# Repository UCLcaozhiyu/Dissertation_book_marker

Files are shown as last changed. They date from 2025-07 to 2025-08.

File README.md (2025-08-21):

#  From Smart Bookmark to Intelligent Bookstand Low-Power Embedded System Design for Enhanced Paper-Based Reading

An intelligent reading-time tracking device based on ESP32 that automatically recognizes different books through NFC, records reading time, and provides Pomodoro timer, statistical analysis, and other features.

Originally conceived as an ultra-thin solar-powered smart bookmark, the project evolved into a desktop-style smart bookstand to overcome energy and hardware constraints while enhancing usability and user experience.

##  Key Features

###  Multi-Book Management
- Support for tracking up to 10 books independently
- Automatic book recognition and switching via NFC cards
- Individual reading statistics for each book
- Persistent data storage, no data loss on power off

###  Smart Tracking
- Automatic reading state detection via light sensor
- Real-time reading time recording
- Adaptive Pomodoro timer functionality
- Personalized reading habit analysis

###  Power-Efficient Design
- Smart deep sleep mode (only 10μA power consumption)
- Adaptive wake-up intervals (1-5 minutes)
- Dual wake-up mechanism: GPIO and timer
- Intelligent I2C bus management

###  User Interaction
- 128x64 OLED display
- Pixel art style UI design
- Real-time trend graph of ambient light，dynamic wave animation effects
- Buzzer notifications for reading/rest prompts
- Real-time status indicators

##  Hardware Requirements

### Core Components
- **MCU**: ESP32-C3 / ESP32 WROOM-32D
- **Display**: SSD1306 OLED (128x64, I2C interface)
- **NFC Module**: PN532 (I2C interface)
- **Light Sensor**: Light Dependent Resistor (LDR)
- **Audio**: Active buzzer module (HYT-0905)
- **Power**: BQ24074 charging + Li-ion battery + optional solar panel

Power Options

Monocrystalline solar panel (5V) → sustainable indoor charging

USB Type-C → backup fast charging

Battery: 401020 Li-ion (~120 mAh)

Earlier prototypes attempted OPV flexible solar panels for true bookmark size, but lab tests showed insufficient indoor output (<6 mW @ 500 lux). This led to the shift toward the bookstand form factor with hybrid solar + USB charging.

### Wiring Diagram

```
ESP32 WROOM-32D:
├── OLED SSD1306 (128x64)
│   ├── SDA → GPIO 21
│   ├── SCL → GPIO 22
│   ├── VCC → 3.3V
│   └── GND → GND
├── PN532 NFC Module
│   ├── SDA → GPIO 21 (Shared I2C bus with OLED)
│   ├── SCL → GPIO 22 (Shared I2C bus with OLED)
│   ├── VCC → 3.3V
│   └── GND → GND
├── Light Dependent Resistor (LDR)
│   ├── One end → GPIO 36 (ADC input)
│   ├── Other end → 3.3V
│   └── Pull-down resistor 10kΩ → GND
├── Buzzer Module
│   ├── VCC → 3.3V
│   ├── GND → GND
│   └── Signal → GPIO 5
└── Wake-up Button (Optional)
    ├── One end → GPIO 33
    └── Other end → GND
```

##  Quick Start

### Environment Setup

1. **Install Arduino IDE** (Recommended version 2.0+)
    -Add ESP32 board support via: https://dl.espressif.com/dl/package_esp32_index.json

3. **Add ESP32 Board Support**:
   - File → Preferences → Additional Boards Manager URLs
   - Add: `https://dl.espressif.com/dl/package_esp32_index.json`
   - Tools → Board → Boards Manager → Search "ESP32" and install

4. **Install Required Libraries**:
   ```
   - Adafruit GFX Library
   - Adafruit SSD1306
   - Adafruit PN532
   - ESP32 Preferences
   ```

### Compile and Upload

1. **Select Board**:
   - ESP32 WROOM-32D: `ESP32 Dev Module`
   - ESP32-C3: `ESP32C3 Dev Module`

2. **Configure Parameters**:
   ```
   Upload Speed: 921600
   CPU Frequency: 240MHz (ESP32) / 160MHz (ESP32-C3)
   Flash Mode: DIO
   Flash Size: 4MB
   Partition Scheme: Default 4MB
   ```

3. **Choose Version**:
   - `bookstand v3/bookstand_WROOM_withbetterNFCmanagement/` - ESP32 WROOM-32D version
   - `bookstand v3/WROOM32Ddeepsleepmode/` - Deep sleep optimized version
   - `bookstand v3/finalOLEDtest/finalOLEDv3/` - ESP32-C3 version

##  Functionality

### NFC Book Management
- Place NFC card above the device for automatic book recognition
- First-time use automatically registers new books
- Support for custom book names and information
- Independent timing and statistics for each book

### Reading Detection
- Automatic reading state detection via light sensor
- Smart filtering of ambient light interference
- Adaptive threshold adjustment
- Real-time status feedback

### Pomodoro Timer
- Automatically adjusts duration based on personal reading habits
- Audio notification when timer expires
- Smart break time suggestions
- Focus concentration statistics

### Data Statistics
- Total reading time for each book
- Average reading session duration
- Reading frequency analysis
- Number of completed Pomodoro sessions

##  Advanced Configuration

### Sensor Calibration

Modify in `bookstand_WROOM_withbetterNFCmanagement.ino`:

```cpp
// Light threshold configuration
const int baselineThreshold = 500;    // Base light threshold
const int dynamicRange = 200;         // Dynamic range
const int noiseMargin = 50;           // Noise margin

// Sleep configuration
const unsigned long idleTimeout = 30000;        // Idle timeout (milliseconds)
const unsigned long lowLightSleepDelay = 2000;  // Low light delay (milliseconds)
```

### Book Management

```cpp
#define MAX_BOOKS 10              // Maximum number of books
#define BOOK_NAME_MAX_LENGTH 20   // Maximum book name length
```

### Deep Sleep Optimization

Enable deep sleep functionality to reduce standby power consumption to 10μA:

```cpp
// In WROOM32Ddeepsleepmode version
const unsigned long wakeupInterval = 60000;  // Wake-up interval (milliseconds)
```

## 📊 Version History
| Version | Key Features | Status |
| --- | --- | --- |
| **Bookmark (v1)** | Ultra-thin OPV-powered design, BLE output | ❌ Energy infeasible |
| **Bookstand v1**  | Dock charging, FSR sensor | Deprecated |
| **Bookstand v2**  | OLED + NFC + Pomodoro + solar + Type-C | ✅ Exhibition-tested |
| **Bookstand v3**  | Multi-book tracking, adaptive Pomodoro, I²C arbitration | ✅ Current release |

### v3.0 - Multi-Book Management Version
- ✅ Support for tracking up to 10 books independently
- ✅ Improved NFC management system
- ✅ Book statistics data persistence
- ✅ Smart book switching notifications

### v2.3 - Deep Sleep Optimization
- ✅ True deep sleep mode (10μA power consumption)
- ✅ Smart timer wake-up
- ✅ Adaptive wake-up intervals
- ✅ GPIO wake-up support

### v2.0 - NFC Multi-Book Support
- ✅ NFC card book recognition
- ✅ Independent timing for multiple books
- ✅ OLED pixel art interface
- ✅ I2C bus conflict optimization

## User Study & Feedback

As part of project evaluation, user questionnaires were conducted during an exhibition:

Positive response to reviving obsolete but aesthetically unique objects (e.g., bookmarks, cassette players) with IoT intelligence.

Users preferred standalone functionality (OLED display, buzzer feedback) over BLE-only smartphone integration.

Bookstand v2 was rated the most popular design:

Artistic shell design

Simple & intuitive UI

Reliable NFC book switching

## Research Context

This project originated as a MSc Dissertation at UCL CASA (Connected Environments).

Explores IoT-enablement of traditional reading tools

Tests feasibility of solar-assisted embedded systems in micro form factors

Investigates balance between traditional aesthetics and smart functionality

Informs future IoT retrofits for legacy objects

Related literature includes indoor photovoltaics, low-power embedded system design, and user acceptance of IoT-enabled traditional objects.

## 🐛 Troubleshooting

### Common Issues

**Q: OLED display not working**
- Check I2C connection wires are correct
- Confirm OLED address is 0x3C
- Check power supply is normal

**Q: NFC cannot read cards**
- Confirm PN532 module I2C mode jumper settings
- Check for I2C address conflicts with OLED
- Try different types of NFC cards

**Q: Light detection inaccurate**
- Adjust LDR position to avoid obstruction
- Modify light threshold parameters in code
- Confirm pull-down resistor value is 10kΩ

**Q: Cannot wake up from deep sleep**
- Check GPIO33 pin connection
- Confirm pull-up resistor configuration is correct
- Verify deep sleep wake-up source settings

### Debug Mode

Enable serial debug information:
```cpp
Serial.begin(115200);
// Add debug output in setup()
Serial.println("=== Debug Mode Enabled ===");
```

##  Contributing

Issues and Pull Requests are welcome!

### Development Environment
- Arduino IDE 2.0+
- ESP32 Arduino Core 2.0+
- Git version control

### Commit Convention
- Feature improvements: `feat: add new feature description`
- Bug fixes: `fix: fix issue description`
- Documentation updates: `docs: update documentation content`

##  License

This project is licensed under the MIT License - see the [LICENSE](LICENSE) file for details.

##  Author

**Zhiyu Cao** - Embedded developer and reading enthusiast

##  Acknowledgments

- Adafruit - Excellent hardware library support
- ESP32 Community - Rich development resources
- All testers for valuable feedback

---

**📖 Enjoy smart reading time! If this project helps you, please give us a ⭐️**

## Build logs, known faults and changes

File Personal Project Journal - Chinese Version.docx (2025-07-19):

Intelligent Bookmark for Reading Time Monitoring using Solar Energy and ESP32-C3

设计一款自供电的智能书签设备，通过太阳能供电与ESP32-C3模块，在无人工干预的情况下记录用户的阅读时间与充电数据，并通过BLE连接与手机App通信。

# 系统设计组成

### 1. 供电与能量管理模块

- 电池：401020 锂电池（容量约100mAh）
- 充电管理：TP4056 充电模块（含过充/过放保护版本）
- 能源来源：
  - 太阳能板（柔性、薄型，适配书签厚度限制）
    - 选型偏向 OPV（有机光伏） 或 Amorphous Silicon（非晶硅）
    - OPV 在低光（室内300–500 lux）条件下有更好表现

### 2. 核心控制器

- MCU：ESP32-C3
  - 具备低功耗能力（支持 deep sleep）
  - 支持 BLE通信 与后续数据传输
  - Type-C口供电调试

### 3. 传感系统与记录逻辑

- 主要机制：通过光照变化判断阅读状态
  - 在有光时 → 正在阅读 → 开始计时并记录太阳能充电数据
  - 在无光时 → 书签被夹进书中 → 暂停计时

### 4. 通信接口

- BLE与手机App连接（如Flutter开发）
  - 数据同步（阅读时长、电量记录）
  - 可视化历史趋势图（选项）

# 设计方案与变体

方案 | 描述 | 优势 | 挑战
柔性OPV太阳能板 | 有机材料，轻薄可弯曲 | 适合室内低光；可集成于书签 | 转换效率较低（5-10%）
非晶硅太阳能板 | 成本低，能适应弯曲 | 室内适用，厚度可控 | 效率略低于OPV，部分厚度超标
CIGS | 效率高，性能稳定 | 适合高强度照明 | 厚度大，不适合书签

状态检测逻辑

方法 | 描述 | 评估
环境光判断 | 利用ESP32连接光敏电阻/光照模块检测光线强度 | 简单可实现；易受遮挡/自然光干扰
时间窗口判断 | 设定连续处于亮光状态达x分钟才记录为阅读 | 可排除短暂曝光，逻辑更稳健
加速度计 | 判断书签是否被移动 | 精度低，不如光照直接

通信与数据处理逻辑

方法 | 描述 | 评估
本地记录 + BLE同步 | ESP32记录数据，定时唤醒上传 | 节能有效
实时BLE传输 | 实时传输充电和阅读状态 | 需保持通信活跃，耗电高
离线+日志同步 | 书签离线记录，用户打开App才触发BLE同步 | 更节能，适合日常使用

# 关键技术假设与论证

1. OPV在室内优于硅材料的理论基础

- OPV吸收光谱集中于可见光和弱红外区
- 在室内照明下，其 光响应效率高于晶体硅（后者偏向强日照中的UV/IR）
- 文献支持：室内光（300–500 lux）中，OPV转换效率甚至可达10%以上，优于传统PV的1–3%

2. ESP32-C3 Deep Sleep策略可行性

- Deep Sleep电流<10μA
- 利用外部中断（例如光敏模块）唤醒
- 低功耗+间歇记录模式可实现一周以上续航

3. BLE传输足以满足数据同步

- 数据包量小（每天几个数值：开始时间、结束时间、电量）
- BLE连接时间<2s，支持低频率上传
- 手机端App只在打开时需要连接

# 从太阳能供电转向可充电底座的方案转型

在初步原型设计阶段，本项目尝试通过柔性太阳能板与401020锂电池为智能书签供电，以实现完全自持型的嵌入式监测系统。然而，实际计算与文献分析表明，OPV太阳能板在典型室内照度（300–500 lux）下的功率输出仅为0.5–2mW，远远无法覆盖ESP32-C3的唤醒与BLE通信周期所需能耗，除非以极长周期与极限休眠压缩任务。

此外，光照判断阅读状态也存在不稳定性，容易受自然光干扰或书本遮挡影响。为此，系统可靠性与功耗策略亟需重构。

💡 设计转变：引入可充电底座

为解决上述挑战，本阶段提出用“书架形状”的可充电底座取代太阳能供电系统，通过物理归位接触来同步数据并补充能量。该设计具备以下优势：

- 稳定供电：摆脱对不确定室内光源的依赖，使用5V电源为锂电池充电
- 更清晰的阅读行为判断：书签离开底座 → 阅读开始；归位 → 阅读结束，逻辑更自然
- 减少硬件复杂性：太阳能板和发电效率优化过程可取消，简化布线与封装结构
- 增强原型测试友好性：调试时可通过底座直接供电，无需外接Type-C线

⚙️ 底座设计概念

- 结构：垂直支架或斜插式书签插槽，配有2个金属接触点（pogo pin或磁吸接点）
- 供电方式：外部Type-C电源（5V），经由底座直接为书签内TP4056模块供电
- 附加功能（未来拓展）：
  - 霍尔传感器检测归位动作
  - BLE同步器（底座作为中继或充电提醒设备）
  - LED状态灯指示充电与连接状态

状态 | 行为 | 电源策略 | BLE状态
离开底座 | 记录开始 | 电池供电 | 周期广播
回到底座 | 记录结束 + 数据同步 | 开始充电 | 上传数据/待机
长时间无变化 | Deep Sleep | 最小功耗 | 不广播

该设计变更显著增强了系统的可持续运行能力、数据判断准确性与用户交互友好度，也为量产封装与结构设计预留更多空间。它将本项目从实验性能源方案推进为更贴近实际应用场景的工程原型，为后续模型稳定性测试与App联动开发提供保障。

## ESP32C3写入问题

ESP32C3SuperMini data https://www.nologo.tech/product/esp32/esp32c3/esp32c3supermini/esp32C3SuperMini.html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

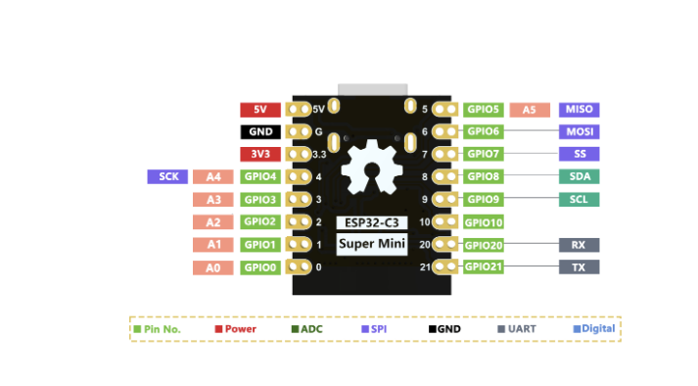
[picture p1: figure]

烧录问题：

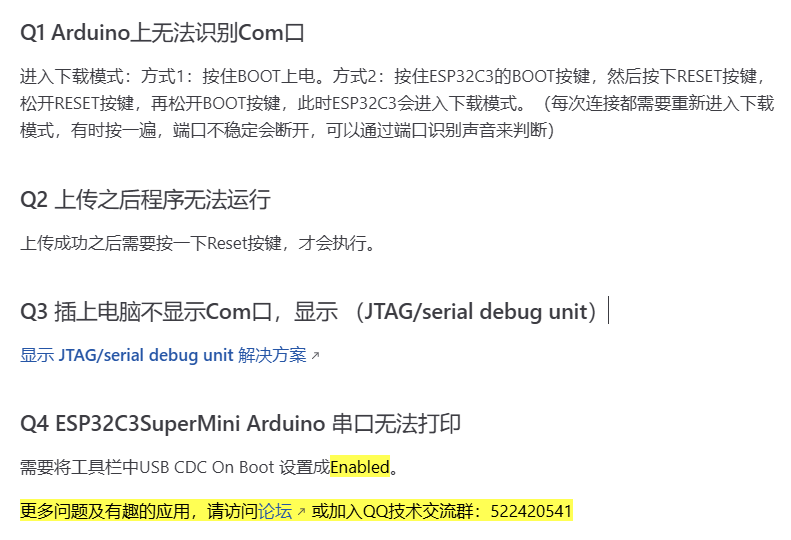
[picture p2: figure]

### 产品成果：

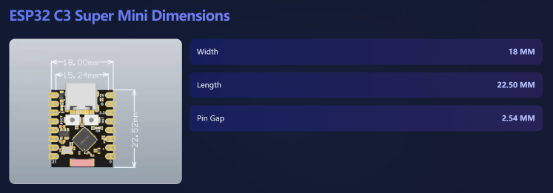
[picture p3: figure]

高度为2mm，测量数据是1.8，但是要考虑误差。

OLED要一个27mm高27.73宽（可设置成28或者更大）厚度为2mm，可以设置成1mm的下沉嵌入结构。

需要购买薄片的光敏电阻或者压感设备。

我计划使用BQ24074模块作为稳压充电模块，在目前的测试中它能在使用OLED, buzzer以及LDR的情况下稳定电压，可以充电和供电，gpt中的ESP32C3阅读提示系统就是这部分内容，我将这个版本认定为3.0版本的产品，它需要完成：一个合适的外壳，看起来像书签，有一个dog site（充电巢），保留检测光照强度和计时的功能，使用深度睡眠功能。使用太阳能板完全替代LDR是不现实的，很多功能受限制，所以购买薄片的光敏电阻更现实。

### Dog site书立

我现在建模的Lacasaparaelpapel是一个书立，它就是我的dogset，在未来我会为它加入灯光效果。给dog site可以增加功能，用压感来检测是否有书本放在上面，

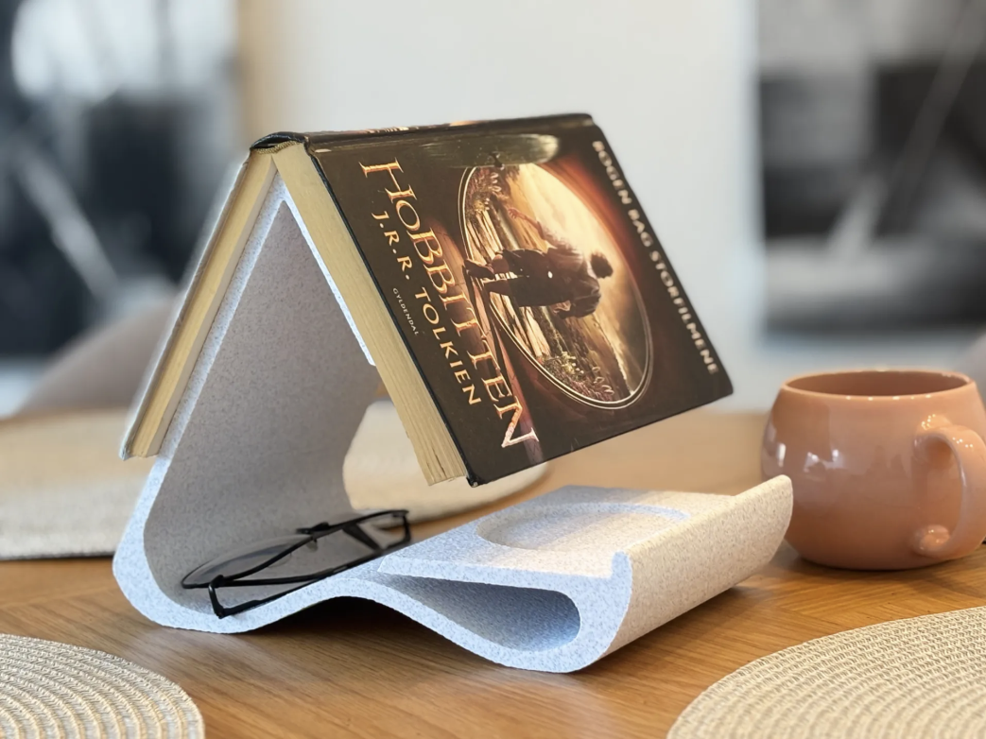
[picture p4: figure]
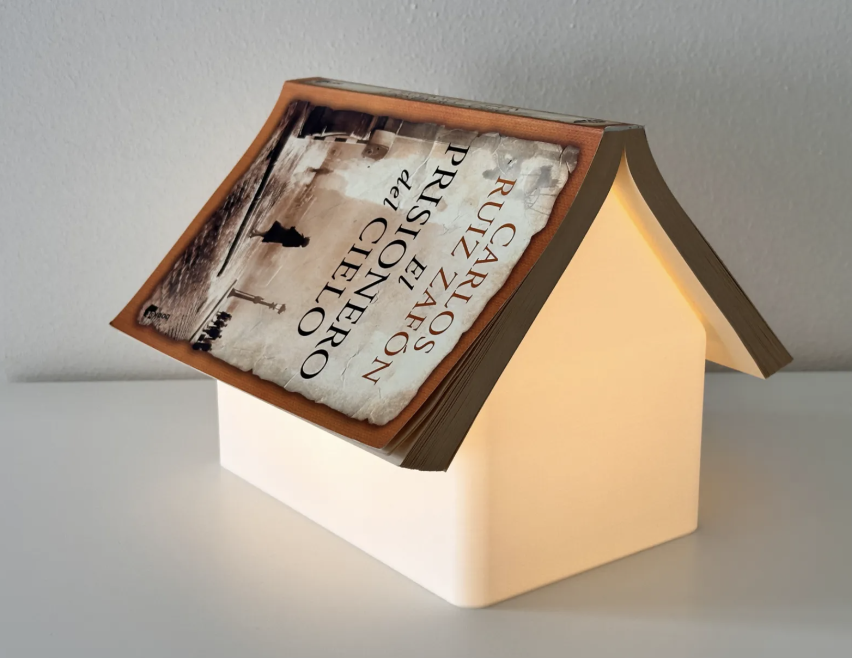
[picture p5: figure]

引入 BQ25570：用于微功率光伏采集的电源管理芯片https://blog.csdn.net/qq_42250136/article/details/146361063

为应对太阳能板在室内环境下电流极低（约 30μA）的挑战，现阶段考虑采用 TI 推出的 BQ25570 作为微功率能量采集与电池充电管理芯片。与 TP4056 相比，BQ25570 更适用于μW~mW 级别的输入功率场景，具备以下关键特性：

- 超低启动电压门槛：最低可在输入功率仅 15μW（典型）时启动升压；
- MPPT（最大功率点跟踪）：动态追踪太阳能板最优输出点，提升充电效率；
- 支持单节锂电池（如 401020）慢充：集成充电终止、电压门限设置、电池保护机制；
- 双输出模式：支持为主控芯片提供稳定系统电压（如 3.3V），同时维持电池充电过程；
- 超低静态功耗：系统休眠功耗低至 330nA，适合低频唤醒、间歇采样与BLE传输场景。

结合 TI官网BQ25570技术文档 (https://www.ti.com/product/BQ25570)，该芯片成为在本项目3.x版本迭代中探索“持续环境能量采集 + 小容量电池缓冲供电”路径的核心候选方案。后续将尝试通过 BQ25570 替代 TP4056，构建无需额外外部稳压模块的集成型能量管理子系统，目标是实现：

- 室内环境下的持续供电维持；
- 间歇工作、BLE广播等任务的低功耗策略；
- 对锂电池的安全慢速充电过程管理；
- 逐步脱离对外部供电底座（dog site）的依赖。

本方案仍需评估实测下电流/功耗波动、系统整体运行时长，以及与ESP32-C3唤醒周期的匹配程度。

我还需要增加更多的功能，让智能书签更智能：一下是一些想法

4. BLE 配对同步阅读数据

描述：通过蓝牙将累计阅读时间、本次阅读时间等传送到手机或 PC。

- 实现方式：
  - 使用 NimBLE 库或 ESP32 BLE 库广播或建立连接。
- 智能价值：可远程查看进度，利于长期记录。
- 实现难度：中–高

✅ 5. 光照趋势图显示（mini折线图）

描述：在 OLED 上显示 30 秒内光照变化曲线，用来感知环境变化或检测是否背光阅读。

- 实现方式：
  - 用一个小 circular buffer 记录光强数值，动态刷新 OLED。
- 智能价值：新颖视觉反馈，教育用户注意用眼卫生。
- 实现难度：中等

✅ 6. 智能学习习惯：自动调整番茄时间

描述：根据用户每次阅读实际平均时长动态调整番茄时长（比如从25分钟变成22分钟）。

- 实现方式：
  - 记录多轮阅读时长取均值，逐步调节。
- 智能价值：个性化时间管理。
- 实现难度：中等–高

✅ 7. 阅读状态提示动画

描述：OLED 上增加简易“阅读中”“休息中”动画（比如跳动的时钟、闭眼图标等）

- 实现方式：
  - 预制小图标或字模切换。
- 智能价值：增强趣味性与交互性。
- 实现难度：低

✅ 8. 防遗失提示（超时警告）

描述：长时间未使用（如超过48小时），短暂唤醒蜂鸣器提示用户“是否忘记继续阅读”。

- 实现方式：
  - RTC+EEPROM记录上次阅读时间，定时唤醒判断是否超时。
- 智能价值：提升用户粘性。
- 实现难度：中等

自适应番茄时间的逻辑有一个严重的问题，就是Pomodoro的时间只会减少不会变多啊！GPT上的最后一版代码还未尝试。

开发日志：智能阅读书签项目功能优化（2025年6月26日）

今日围绕智能书签系统进行了系统性功能扩展与性能优化，主要成果如下：

🧠 功能增强与用户体验优化

1. 自适应 Pomodoro 番茄时长机制优化
  - 引入动态调整策略：若用户完成上一次 Pomodoro，则自动增长 5 分钟，最多 60 分钟；
  - 若未完成，则基于历史阅读平均值动态回退，但最低不低于 5 分钟；
  - 番茄目标时长可持久化存储，并通过 EEPROM 保留历史行为数据。
2. OLED 状态文案与页面恢复
  - 恢复了所有提示文案（如“Start reading”“Low light”“Pomodoro done”等），让用户在不同阅读状态下获得明确指引；
  - 修复了页面被趋势图覆盖的问题，实现提示与图形分层渲染。
3. 光照趋势图（Light Trend）与建议亮度（Best Lux）
  - 实现实时滚动折线图展示近 30 秒光照强度；
  - 新增 Best Lux 建议值计算，采用指数移动平均（EMA）算法，并加边界限制（100–3000 lux）；
  - 建议亮度位置调整至图表顶部区域，不干扰主图显示。
4. 多帧书本翻页动画（失败了，动画展现效果很难表达，这对代码是一个很大的挑战，我放弃）
  - 重构并集成了三帧“书本翻页”图案动画，形象地表示“正在阅读”状态；
  - 动画逻辑与 UI 提示并行渲染，增强趣味性与视觉反馈。
5. 阅读总时长显示增强
  - 原本只显示“分钟”，现支持总阅读时间以“xh ym”格式显示，便于长时阅读记录；
  - 动态调整单位显示逻辑，避免数值溢出或不直观。
6. 番茄结束后的休息机制修复
  - 修复原有“休息时间仅持续几秒”的问题；
  - 保证完成番茄后进入 5 分钟稳定休息期，并保持提示动画及文案可视。

🧪 测试与验证

- 实地测试了在正常阅读、光线不足、书签夹入、进入睡眠、完成番茄后的每个状态切换；
- 验证了 OLED 显示逻辑、动画流畅度、Best Lux 趋势稳定性；
- 检查 EEPROM 写入是否稳定，并确保休眠前完成持久化存储操作。

🟢 当前版本代码已集成全部功能，准备部署测试下一阶段（如 BLE 同步、亮度调节推荐、习惯分析等）。整体系统已具备完整可视反馈、自适应学习能力与低功耗调度机制，满足长期使用与用户友好需求。

Canvas上最后一版代码还未测试。

### NFC和RFID

我加入了MF RC522 RFID 模块让设备可以阅读书本的ID，我以此得知书本的名字和页数。RC552好像和OLED屏幕之间互相有干扰。

更换为PN532之后又出现了找不到串口的问题。

我进行了一些尝试，我在IDE安装了Adafruit_PN532库，并从Github下载并安装了NDEF Library for Arduino（https://github.com/don/NDEF）。

安装 NDEF Library for Arduino 的方法（适用于 Arduino IDE）

步骤如下：

1. 打开这个 GitHub 项目链接： https://github.com/don/NDEF
2. 点击右上角绿色按钮【Code】→ 选择【Download ZIP】
3. 下载完成后，回到 Arduino IDE：
  - 点击菜单栏 → 工具 → 管理库（不是这里！）
  - 而是点击菜单栏 → 库 > 添加 .ZIP 库（Add .ZIP Library）
4. 选择刚才下载的 NDEF-master.zip，IDE 会自动安装。

安装成功后你会看到：

在 Arduino IDE 的菜单：

文件 → 示例 → NDEF
会出现相关示例，如 ReadTag, WriteTag, NdefMessageParser 等。

⚠️ 注意事项

- NDEF 库必须 配合 Adafruit_PN532 一起使用，否则无法读取；
- 它主要支持 NFC Forum Type 2 标签（NTAG213、215、216）；
- 如果你用的是手机模拟 NFC 标签，也必须确保写入的是 NDEF 文本/URL 格式。

还需要一个PN532_I2C.h的库。

正确安装 PN532_I2C.h 所属的库

这个头文件来自于 GitHub 上的库：

📦 库名称：Seeed-Studio/PN532

📎 GitHub 地址：https://github.com/Seeed-Studio/PN532

安装方法（适用于 Arduino IDE）

方法 1：通过 .zip 安装

1. 打开链接：https://github.com/Seeed-Studio/PN532
2. 点击绿色按钮 Code → Download ZIP
3. 回到 Arduino IDE → 菜单栏选择：项目 → 添加库 → 添加 .ZIP 库
4. 选择刚下载的 PN532-master.zip，导入即可。

GPT上最后一版代码没试过。之前的代码使用的是I2C的链接方式，而板子上的接线是SPI。不行啊，用不了IDE不应用我下的库啊。这个方案应该是不可行的，但是NDEF是完成NFC的txt文字读取的关键，我认为在后续的开发中可以进一步研究这个库。

现在的计划是先使用rc522读取UID,在中控中记录对应UID代表的书名和页数，同时尝试使用PN532，理论上PN532可以读取TXT文档，在对应的GIThub中有提到。

成了，RC522的代码中现在集成了OLED。

但是写入任然会出现问题。

我的下一步计划是尝试水墨屏和PN532 I2C协议。

PN532 I2C协议成功了，使用的是同名代码，也就是说我用的是I2C协议，这会多占用线。可以用回OLE，这样我只要在I2C做好隔离就可以节省pin口，为未来的开发，增加部件留下余地。

用epaper有一个好处啊，就是文字就算是断电了也会保留，很多东西不用存到本地了。

1. NFC 与 OLED 模块冲突排查

- 使用 MFRC522 RFID 模块，与 OLED 同时运行时出现 I2C 通信干扰，导致 OLED 无法正常刷新。
- 尝试替换为 PN532 NFC 模块，安装 Adafruit_PN532 库 + NDEF Library for Arduino 读取 NDEF 文本数据，但 I2C 与 SPI 接线存在不兼容问题，导致无法稳定通信。

解决方案：使用 I2C 总线互斥锁 + 降低 NFC 轮询频率，避免 OLED 与 NFC 同时访问总线产生 I2C transaction unexpected nack detected 错误。（有效）

2. 界面优化与像素图标设计

- 原先的书本动画采用简单的 display.fillRect，表现效果较差。
- 新增 16x16像素 PROGMEM 位图图标（书本、心形、时钟、电池、星星），让 OLED 页面更有视觉吸引力。
- 在 Light Trend 页面新增标语：

“Please do not read in the dark. Look for light.”

- NFC 页面增加 书籍信息显示，将 Last Book 固定替换为 “my notebook”。

3. I2C 设备检测与调试结果

- 通过 I2C 扫描器确认：
  - OLED → 地址 0x3C
  - PN532 → 地址 0x24
- 初始化后正常显示固件版本 1.6，但读取 NFC 卡 UID 时出现 I2C 冲突 → 已通过互斥访问解决，错误大幅减少。

4. 硬件接线与功耗考虑

- OLED 与 PN532 共用 SDA/SCL 总线（GPIO 8/9），需额外 4.7kΩ 上拉电阻保证信号完整性。（并不需要，我已经证实没有这问题了）
- 未来计划将 NFC 接口改用 SPI，避免与 OLED I2C 冲突。
- 继续优化 ESP32C3 深度睡眠功耗，保证阅读书签续航。

5. 未来改进方向

- 尝试 水墨屏（e-paper） 替代 OLED，让文字在断电后仍能保留，减少存储和刷新功耗。（水墨屏刷新率太低了，无法满足大量信息输出的要求）
- 继续验证 PN532 I2C 模式读取 TXT 文本，尝试直接解析书名和页数信息。
- 如果 PN532 功能不满足需求，保留UID 识别方案，在中控中手动映射 UID→书名。

✅ 本阶段成果

- NFC 识别、OLED 显示、光照检测三者集成完成，I2C 冲突基本解决。
- 界面增加提示标语与像素装饰，交互体验提升。
- 书籍 UID 读取与书名映射已初步可用，未来可结合 BLE 同步数据。

FinalOLEDtest.ino：

初次设置：

1. 上传代码到ESP32
2. 打开串口监视器 (115200波特率)
3. 设备会显示初始化状态

日常使用：

1. 放置NFC卡 - 将代表某本书的NFC卡靠近设备
  - 设备会检测卡片并显示书籍信息
  - 播放两声提示音确认识别
2. 开始阅读 - 在充足光线下开始阅读
  - 屏幕显示当前阅读时间
  - 显示当前书籍信息和累计时间
3. 暂停阅读 - 光线变暗时自动暂停
  - 显示光线趋势图
  - 播放长声提示音
4. 结束阅读 - 移除NFC卡或进入深度睡眠
  - 自动保存阅读数据
  - 设备进入低功耗模式

电源管理

- 活跃状态: 正常工作，NFC检测每2秒一次
- 暂停状态: 显示趋势图，降低功耗
- 深度睡眠: 极暗环境下自动进入，10秒后唤醒

## OLED页面美化：

像素艺术界面：阅读模式页面

- 大字体显示当前时间 (分:秒)
- 动态轮播图标 (每20帧切换)
- 番茄钟进度条显示
- NFC状态指示灯
- 装饰边框

光线趋势页面

- 电池图标表示传感器状态
- 重新布局的趋势曲线
- 底部装饰点线

NFC检测页面

- 书本 + 心形图标组合
- UID信息分行显示
- 装饰圆点底部

休息页面

- 心形 + 星星图标
- 剩余休息时间显示
- 动态波浪线装饰 (使用sin函数)

睡眠页面

- 电池 + 时钟图标
- "Z z z" 睡眠提示
- 倒计时显示

## 自适应番茄钟算法优化

(better_Pomodoro.ion)

日期： 2025-01-16
模块： 自适应番茄钟系统
类型： 算法优化

🔍 问题分析

在代码review过程中，发现原有的自适应番茄钟算法存在以下问题：

原算法缺陷：

1. 非对称调整：完成时固定+5分钟，未完成时直接跳到历史平均值
2. 数据偏差：只有"未完成"的会话计入历史统计，导致数据不准确
3. 剧烈跳跃：缺乏平滑过渡机制，目标时长变化过于突然
4. 用户体验差：可能造成挫败感或过于保守的目标设定

算法行为示例：

初始: 25分钟 → 完成 → 30分钟 → 完成 → 35分钟 → 失败20分钟 → 直接跳到20分钟

🚀 算法重构

新算法特点：

- 平滑调整：引入学习率(15%)控制变化幅度
- 差异化策略：根据完成率进行分层处理
- 双向记录：所有会话都计入历史数据
- 渐进式学习：避免剧烈跳跃，更符合用户习惯

平滑过渡：

- 使用学习率 (15%) 控制调整幅度
- 避免目标时长剧烈跳跃
- 渐进式学习用户习惯

双向记录：

- 所有会话都计入历史数据
- 避免只记录"失败"案例的偏差
- 更准确反映用户真实能力

智能感知：

- 根据完成率进行差异化处理
- 超额完成 → 积极增长
- 表现稳定 → 维持现状
- 完成困难 → 降低难度

详细反馈：

- 完整的调整日志
- 显示完成率、历史平均、新目标
- 便于理解算法行为

核心参数设计：

const float LEARNING_RATE = 0.15; // 学习率：控制调整幅度

const float SUCCESS_GROWTH = 1.05; // 成功完成时增长5%

const float PARTIAL_GROWTH = 1.02; // 部分完成时增长2%

const float ADJUST_RATE = 0.8; // 未完成时调整系数

分层调整策略：

完成率 | 调整策略 | 增长/调整幅度 | 用户反馈
≥120% | 较大增长 | +5% | "超额完成，挑战更高目标"
100-120% | 小幅增长 | +2% | "正常完成，稳步提升"
80-100% | 微调维持 | 向历史平均微调 | "表现稳定，维持现状"
60-80% | 适度调整 | 降低20% | "需要降低难度"
<60% | 显著调整 | 降低30% | "明显降低目标，重建信心"

💻 技术实现

关键代码变更：

// 新增：差异化完成率处理

float completionRate = (float)sessionMillis / (float)adaptivePomodoroMillis;

// 新增：所有会话数据记录

adaptiveTotalSessionTime += sessionMillis; // 成功和失败都记录

adaptiveSessionCount++;

// 新增：平滑调整公式

adaptivePomodoroMillis = (unsigned long)(LEARNING_RATE * targetAdjustment +

(1 - LEARNING_RATE) * adaptivePomodoroMillis);

完整思路：

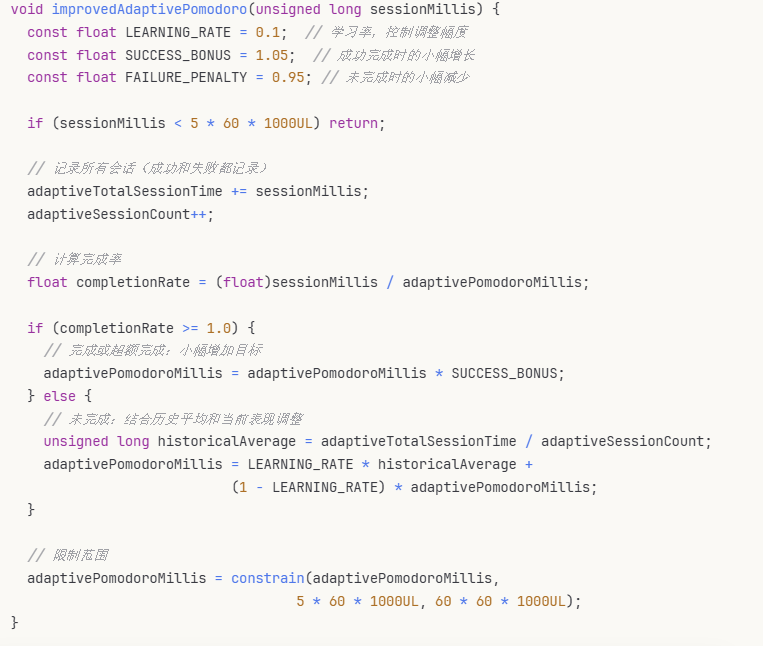
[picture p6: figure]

调试增强：

- 添加详细的分层日志输出
- 显示完成率、历史平均、调整原因
- 便于算法行为分析和调试

情况1：用户能力提升 目标25分钟 → 完成30分钟(120%) → 目标变为26.25分钟 (+5%)

情况2：表现稳定 目标25分钟 → 完成22分钟(88%) → 目标微调至24.5分钟

情况3：需要调整 目标25分钟 → 完成12分钟(48%) → 目标调整至18分钟

情况4：逐步适应 经过10次会话后，目标会收敛到用户的真实能力水平

📊 预期效果

用户体验提升：

1. 更贴合实际：目标时长更符合个人阅读能力
2. 激励机制：超额完成有正向反馈，建立成功习惯
3. 渐进学习：避免挫败感，目标调整更加平滑
4. 数据透明：详细反馈帮助用户了解进展

算法收敛性：

- 经过10-15次会话后，目标会收敛到用户真实能力水平
- 随着用户能力提升，算法会自动调整挑战难度
- 避免停留在舒适区，保持适度挑战

🔧 后续优化计划

1. A/B测试：收集用户反馈，验证算法效果
2. 参数调优：根据实际使用情况微调学习率和增长因子
3. 趋势分析：考虑加入时间序列分析，识别用户能力变化趋势
4. 个性化：根据用户类型(学生/职场人士)调整算法参数

📝 备注

- 兼容性：新算法向后兼容，不影响现有存储数据
- 性能：计算复杂度仍为O(1)，无性能影响
- 测试：建议在实际使用中观察1-2周，验证算法效果

提交者： AI Assistant
审核状态： 待测试
影响范围： 自适应番茄钟模块

# 可加入的系统：

自定义设置

调整参数：

cpp

const int lightThreshold = 1000; // 阅读光线阈值

const int bookmarkThreshold = 50; // 睡眠光线阈值

const unsigned long NFC_CHECK_INTERVAL = 2000; // NFC检查间隔

const unsigned long restDuration = 5 * 60 * 1000UL; // 休息时长

这个系统让你可以用不同的NFC卡代表不同的书籍，自动追踪每本书的阅读时间，非常适合读书爱好者使用！

使用ESP32-WROOM-32 可以满足GPIO外部唤醒的设计：

ESP32 ULP 唤醒 ADC 理论 & 论文/文档支持

1️⃣ Espressif 官方文档

- ESP32 Technical Reference Manual (TRM)
  - Chapter ULP Coprocessor：ULP 协处理器在深度睡眠期间可以读取 RTC IO、RTC ADC 并作逻辑判断
  - 可以触发 ulp_wakeup → 唤醒主 CPU

2️⃣ Espressif 官方示例

- esp-idf/examples/system/ulp_adc
  - 演示了 ULP 定时采样 ADC，如果电压超出阈值 → 唤醒主核
  - 用法和你的光线检测完全一致，只要换成 LDR 分压输入就可以

3️⃣ 学术论文/案例

- “Energy-Efficient Ambient Monitoring with ESP32 ULP Coprocessor”（IoT workshop论文）
  - ULP ADC 采样环境光和温度，功耗降低 90%
- “Low-Power Environmental Sensing with ESP32 ULP”（社区研究）
  - ULP 以 150µA 工作，主核深度睡眠 <10µA
- 很多低功耗传感节点案例都用 ULP 做光线/声音门限唤醒

📌 结论：官方确实支持，并有实际论文 & 案例证明可行

这样就可以不需要定期唤醒检测ldr读数了，可以更省电。也可以避免反复重置oled和RFID.

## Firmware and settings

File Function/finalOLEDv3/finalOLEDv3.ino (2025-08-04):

/*
 * =======================================================================
 * ESP32C3 NFC智能阅读追踪器 v2.0
 * =======================================================================
 * 
 * 功能特色：
 * - NFC卡片识别不同书籍，分别记录阅读时间
 * - 光线传感器自动检测阅读状态
 * - 自适应番茄钟功能，根据阅读习惯调整时长
 * - 精美像素艺术OLED界面设计
 * - 数据持久化存储
 * - I2C总线冲突优化
 * 
 * 硬件连接：
 * ESP32C3 开发板:
 * ├── OLED SSD1306 (128x64)
 * │   ├── SDA → GPIO 8
 * │   ├── SCL → GPIO 9
 * │   ├── VCC → 3.3V
 * │   └── GND → GND
 * ├── PN532 NFC模块
 * │   ├── SDA → GPIO 8 (与OLED共享I2C总线)
 * │   ├── SCL → GPIO 9 (与OLED共享I2C总线)
 * │   ├── VCC → 3.3V
 * │   └── GND → GND
 * ├── 光敏电阻 (LDR)
 * │   ├── 一端 → GPIO 0 (ADC输入)
 * │   ├── 另一端 → 3.3V
 * │   └── 下拉电阻10kΩ → GND
 * └── 蜂鸣器模块
 *     ├── VCC/+ → 3.3V (红线)
 *     ├── GND/- → GND  (黑线)
 *     └── I/O/S → GPIO 5 (信号线)
 * 
 * 作者: AI Assistant
 * 更新日期: 2025-01-16
 * =======================================================================
 */

// ===== 库文件引入 =====
#include <Arduino.h>           // Arduino核心库
#include "driver/ledc.h"       // ESP32 LEDC PWM驱动 (蜂鸣器控制)
#include <Preferences.h>       // ESP32非易失性存储库
#include <Wire.h>              // I2C通信库
#include <Adafruit_GFX.h>      // Adafruit图形库
#include <Adafruit_SSD1306.h>  // OLED显示屏驱动
#include "esp_system.h"        // ESP32系统函数
#include "esp_sleep.h"         // ESP32深度睡眠功能
#include <Adafruit_PN532.h>    // PN532 NFC模块驱动
#include <math.h>              // 数学函数库 (用于波浪线动画)

// ===== 硬件引脚定义 =====
#define SCREEN_WIDTH 128       // OLED屏幕宽度 (像素)
#define SCREEN_HEIGHT 64       // OLED屏幕高度 (像素)
#define OLED_RESET -1          // OLED复位引脚 (-1表示使用软件复位)
#define SCREEN_ADDRESS 0x3C    // OLED的I2C地址

#define SDA_PIN 8              // I2C数据线引脚 (SDA)
#define SCL_PIN 9              // I2C时钟线引脚 (SCL)

const int ldrPin = 0;          // 光敏电阻连接的ADC引脚
const int piezoPin = 5;        // 蜂鸣器连接的PWM引脚

// ===== 传感器阈值配置 =====
const int lightThreshold = 1000;    // 光线阈值：高于此值认为在阅读
const int bookmarkThreshold = 50;   // 书签阈值：低于此值进入深度睡眠
const uint64_t uS_TO_S_FACTOR = 1000000ULL;  // 微秒到秒的转换因子
const int TIME_TO_SLEEP = 10;       // 深度睡眠时间 (秒)

// ===== 像素图标数据 (16x16像素，单色位图) =====
// 📚 书本图标 - 用于表示书籍和阅读
const unsigned char icon_book[] PROGMEM = {
  0x00, 0x00, 0x1F, 0xF8, 0x10, 0x08, 0x10, 0x08, 0x10, 0x08, 0x10, 0x08, 
  0x1F, 0xF8, 0x10, 0x08, 0x10, 0x08, 0x10, 0x08, 0x10, 0x08, 0x10, 0x08, 
  0x10, 0x08, 0x1F, 0xF8, 0x00, 0x00, 0x00, 0x00
};

// 🕐 时钟图标 - 用于表示时间和计时
const unsigned char icon_clock[] PROGMEM = {
  0x03, 0xC0, 0x0C, 0x30, 0x10, 0x08, 0x20, 0x04, 0x20, 0x04, 0x41, 0x82, 
  0x41, 0x82, 0x41, 0x02, 0x41, 0x02, 0x20, 0x04, 0x20, 0x04, 0x10, 0x08, 
  0x0C, 0x30, 0x03, 0xC0, 0x00, 0x00, 0x00, 0x00
};

// ❤️ 心形图标 - 用于表示喜爱和欢迎
const unsigned char icon_heart[] PROGMEM = {
  0x00, 0x00, 0x0E, 0x70, 0x1F, 0xF8, 0x3F, 0xFC, 0x7F, 0xFE, 0x7F, 0xFE, 
  0x3F, 0xFC, 0x1F, 0xF8, 0x0F, 0xF0, 0x07, 0xE0, 0x03, 0xC0, 0x01, 0x80, 
  0x00, 0x00, 0x00, 0x00, 0x00, 0x00, 0x00, 0x00
};

// ⭐ 星星图标 - 用于装饰和成就感
const unsigned char icon_star[] PROGMEM = {
  0x01, 0x80, 0x01, 0x80, 0x01, 0x80, 0x0D, 0xB0, 0x1F, 0xF8, 0x0F, 0xF0, 
  0x07, 0xE0, 0x0F, 0xF0, 0x1B, 0xD8, 0x31, 0x8C, 0x60, 0x06, 0x60, 0x06, 
  0x00, 0x00, 0x00, 0x00, 0x00, 0x00, 0x00, 0x00
};

// 🔋 电池图标 - 用于表示电源状态和传感器
const unsigned char icon_battery[] PROGMEM = {
  0x00, 0x00, 0x3F, 0xF0, 0x20, 0x18, 0x20, 0x18, 0x27, 0x98, 0x27, 0x98, 
  0x27, 0x98, 0x27, 0x98, 0x27, 0x98, 0x27, 0x98, 0x20, 0x18, 0x20, 0x18, 
  0x3F, 0xF0, 0x00, 0x00, 0x00, 0x00, 0x00, 0x00
};

// ===== 硬件对象实例化 =====
Adafruit_SSD1306 display(SCREEN_WIDTH, SCREEN_HEIGHT, &Wire, OLED_RESET);  // OLED显示屏对象
Adafruit_PN532 nfc(SDA_PIN, SCL_PIN);  // PN532 NFC模块对象

// ===== NFC相关变量 =====
String lastUID = "";              // 上次检测到的NFC卡片UID
bool showLastUIDOnBoot = false;   // 启动时是否显示上次UID
bool nfcInitialized = false;      // NFC模块是否初始化成功
bool oledInitialized = false;     // OLED是否初始化成功
bool i2cBusy = false;             // I2C总线互斥标志 (防止冲突)

// ===== 番茄钟配置 =====
const int defaultPomodoroMin = 25;                              // 默认番茄钟时长 (分钟)
unsigned long adaptivePomodoroMillis = defaultPomodoroMin * 60000UL;  // 自适应番茄钟时长 (毫秒)
unsigned long adaptiveTotalSessionTime = 0;                     // 累计会话时间 (用于计算平均值)
unsigned long adaptiveSessionCount = 0;                         // 会话计数 (用于计算平均值)
const unsigned long restDuration = 5 * 60 * 1000UL;           // 休息时间 (5分钟)

// ===== 阅读状态变量 =====
bool isReading = false;           // 当前是否在阅读
bool isPaused = false;            // 是否暂停
bool inRest = false;              // 是否在休息时间
bool isSleeping = false;          // 是否在睡眠状态

// ===== 时间记录变量 =====
unsigned long sessionStartMillis = 0;        // 当前会话开始时间
unsigned long accumulatedSessionMillis = 0;  // 累积的会话时间
unsigned long restStartMillis = 0;           // 休息开始时间
unsigned long totalReadingSeconds = 0;       // 总阅读时间 (秒)

// ===== 数据存储对象 =====
Preferences prefs;  // ESP32非易失性存储对象，用于保存数据到Flash

// ===== 光线趋势分析变量 =====
const int trendSize = 30;        // 趋势数据数组大小
int lightTrend[trendSize] = {0}; // 光线趋势数据数组
int trendIndex = 0;              // 当前趋势数据索引
float bestLuxEMA = 0.0;          // 最佳光照度的指数移动平均值
const float emaAlpha = 0.05;     // EMA平滑系数 (值越小越平滑)
int animationFrame = 0;          // 动画帧计数器

/*
 * =======================================================================
 * 功能函数定义区域
 * =======================================================================
 */

/**
 * I2C设备扫描函数
 * 功能：扫描I2C总线上的所有设备，用于调试硬件连接
 * 输出：通过串口打印找到的设备地址
 */
void scanI2CDevices() {
  Serial.println("Scanning I2C devices...");
  int deviceCount = 0;
  
  // 遍历所有可能的I2C地址 (0x01 到 0x7F)
  for (byte address = 1; address < 127; address++) {
    Wire.beginTransmission(address);
    byte error = Wire.endTransmission();
    
    if (error == 0) {  // 如果设备响应成功
      Serial.print("I2C device found at address 0x");
      if (address < 16) Serial.print("0");  // 补零对齐
      Serial.print(address, HEX);
      Serial.println();
      deviceCount++;
    }
  }
  
  Serial.print("Total devices found: ");
  Serial.println(deviceCount);
}

/**
 * 绘制屏幕四角装饰边框
 * 功能：在OLED屏幕四个角落绘制L形装饰线条
 * 用途：统一的界面风格，增加视觉美感
 */
void drawCornerDecorations() {
  // 左上角 L形
  display.drawLine(0, 0, 8, 0, SSD1306_WHITE);    // 水平线
  display.drawLine(0, 0, 0, 8, SSD1306_WHITE);    // 垂直线
  
  // 右上角 L形
  display.drawLine(119, 0, 127, 0, SSD1306_WHITE); // 水平线
  display.drawLine(127, 0, 127, 8, SSD1306_WHITE); // 垂直线
  
  // 左下角 L形
  display.drawLine(0, 56, 8, 56, SSD1306_WHITE);   // 水平线
  display.drawLine(0, 56, 0, 63, SSD1306_WHITE);   // 垂直线
  
  // 右下角 L形
  display.drawLine(119, 63, 127, 63, SSD1306_WHITE); // 水平线
  display.drawLine(127, 55, 127, 63, SSD1306_WHITE); // 垂直线
}

/**
 * 绘制动态轮播图标
 * 参数：x, y - 图标位置坐标
 *       frame - 当前动画帧数
 * 功能：循环显示4种图标，每20帧切换一次，创造动态效果
 */
void drawAnimatedIcon(int x, int y, int frame) {
  // 图标数组：书本、心形、星星、时钟
  const unsigned char* icons[] = {icon_book, icon_heart, icon_star, icon_clock};
  int iconIndex = (frame / 20) % 4; // 每20帧切换图标 (20帧 ≈ 10秒)
  
  display.drawBitmap(x, y, icons[iconIndex], 16, 16, SSD1306_WHITE);
}

/**
 * 绘制进度条
 * 参数：x, y - 进度条左上角坐标
 *       width, height - 进度条尺寸
 *       progress - 当前进度值
 *       maxProgress - 最大进度值
 * 功能：显示番茄钟进度或其他进度信息
 */
void drawProgressBar(int x, int y, int width, int height, int progress, int maxProgress) {
  // 绘制进度条外框
  display.drawRect(x, y, width, height, SSD1306_WHITE);
  
  // 计算填充宽度
  int fillWidth = (progress * (width - 2)) / maxProgress;
  if (fillWidth > 0) {
    // 绘制进度填充 (内部留1像素边距)
    display.fillRect(x + 1, y + 1, fillWidth, height - 2, SSD1306_WHITE);
  }
}

/**
 * 初始化OLED显示屏
 * 返回：bool - 初始化是否成功
 * 功能：初始化OLED并显示启动动画
 */
bool initializeOLED() {
  // 尝试初始化OLED
  if (!display.begin(SSD1306_SWITCHCAPVCC, SCREEN_ADDRESS)) {
    Serial.println("OLED initialization failed!");
    return false;
  }
  
  // === 启动动画第一屏 ===
  display.clearDisplay();
  
  // 绘制装饰边框
  drawCornerDecorations();
  
  // 显示标题
  display.setTextSize(1);
  display.setTextColor(SSD1306_WHITE);
  display.setCursor(15, 2);
  display.println("Reading Tracker");
  
  // 中央三个图标展示系统功能
  display.drawBitmap(30, 20, icon_book, 16, 16, SSD1306_WHITE);   // 书本：阅读
  display.drawBitmap(50, 20, icon_heart, 16, 16, SSD1306_WHITE);  // 心形：喜爱
  display.drawBitmap(70, 20, icon_clock, 16, 16, SSD1306_WHITE);  // 时钟：计时
  
  // 版本信息
  display.setCursor(45, 45);
  display.println("v2.0");
  
  // 底部装饰点线
  for (int i = 0; i < SCREEN_WIDTH; i += 8) {
    display.drawPixel(i, 55, SSD1306_WHITE);
  }
  
  display.display();
  delay(2000);  // 显示2秒
  
  // === 启动动画第二屏 ===
  display.clearDisplay();
  display.setCursor(35, 20);
  display.println("Starting...");
  display.drawBitmap(56, 35, icon_star, 16, 16, SSD1306_WHITE);
  display.display();
  
  Serial.println("OLED initialized successfully");
  return true;
}

/**
 * 初始化NFC模块
 * 返回：bool - 初始化是否成功
 * 功能：检测PN532模块，获取固件版本，配置SAM
 */
bool initializeNFC() {
  Serial.println("Initializing NFC...");
  nfc.begin();
  
  // 获取固件版本信息
  uint32_t versiondata = nfc.getFirmwareVersion();
  if (!versiondata) {
    Serial.println("PN532 not found!");
    return false;
  }
  
  // 显示固件版本 (格式：主版本.次版本)
  Serial.print("Found PN532, FW ver: ");
  Serial.print((versiondata >> 16) & 0xFF, DEC);
  Serial.print('.');
  Serial.println((versiondata >> 8) & 0xFF, DEC);
  
  // 配置SAM (Security Access Module)
  nfc.SAMConfig();
  Serial.println("NFC initialized successfully");
  return true;
}

/**
 * 将UID字节数组转换为十六进制字符串
 * 参数：uid - UID字节数组
 *       uidLength - UID长度
 * 返回：String - 格式化的UID字符串
 */
String getUIDString(uint8_t* uid, uint8_t uidLength) {
  String uidStr = "";
  for (uint8_t i = 0; i < uidLength; i++) {
    if (uid[i] < 0x10) uidStr += "0";  // 补零对齐
    uidStr += String(uid[i], HEX);
    if (i < uidLength - 1) uidStr += "";  // 可选择是否添加空格分隔
  }
  uidStr.toUpperCase();  // 转换为大写
  return uidStr;
}

/**
 * 加载书籍数据
 * 参数：bookUID - 书籍的UID
 * 功能：从存储中读取指定书籍的阅读时间和名称
 * 注意：当前版本简化实现，可扩展为多书籍管理
 */
void loadBookData(String bookUID) {
  String key = "book_" + bookUID;
  // currentBookSeconds = prefs.getULong(key.c_str(), 0);
  
  // 尝试获取书名，如果没有则使用默认名称
  String nameKey = "name_" + bookUID;
  // currentBookName = prefs.getString(nameKey.c_str(), "Book " + bookUID.substring(0, 4));
}

/**
 * 保存书籍阅读数据
 * 参数：bookUID - 书籍UID
 *       seconds - 阅读秒数
 * 功能：将书籍阅读时间保存到非易失性存储
 */
void saveBookData(String bookUID, unsigned long seconds) {
  String key = "book_" + bookUID;
  prefs.putULong(key.c_str(), seconds);
  Serial.println("Saved book " + bookUID + ": " + String(seconds) + " seconds");
}

/**
 * 保存书籍名称
 * 参数：bookUID - 书籍UID
 *       bookName - 书籍名称
 * 功能：保存自定义书名到存储
 */
void saveBookName(String bookUID, String bookName) {
  String nameKey = "name_" + bookUID;
  prefs.putString(nameKey.c_str(), bookName);
}

/**
 * 关闭OLED显示屏
 * 功能：关闭显示，释放I2C总线，设置引脚为上拉输入模式
 * 用途：进入深度睡眠前的清理工作
 */
void turnOffOLED() {
  if (oledInitialized) {
    display.clearDisplay();
    display.display();
    display.ssd1306_command(SSD1306_DISPLAYOFF);  // 关闭显示
    delay(100);
  }
  Wire.end();  // 释放I2C总线
  
  // 设置I2C引脚为上拉输入，降低功耗
  pinMode(SDA_PIN, INPUT_PULLUP);
  pinMode(SCL_PIN, INPUT_PULLUP);
}

/**
 * 开启OLED显示屏
 * 功能：重新初始化I2C总线和OLED显示屏
 * 用途：从深度睡眠唤醒后恢复显示
 */
void turnOnOLED() {
  Wire.begin(SDA_PIN, SCL_PIN);  // 重新初始化I2C
  delay(100);  // 等待总线稳定
  oledInitialized = initializeOLED();
}

/**
 * 绘制光线趋势图界面 (修改版 - 简化护眼提示)
 * 功能：显示光线传感器数据趋势，用于暂停阅读时的界面
 * 特色：包含电池图标、趋势曲线、装饰元素，以及简洁的护眼提示
 */
void drawTrendGraph() {
  if (!oledInitialized || i2cBusy) return;  // 检查显示状态和I2C总线
  
  display.clearDisplay();
  
  // 绘制装饰边框
  drawCornerDecorations();
  
  // 标题和图标
  display.setTextSize(1);
  display.setTextColor(SSD1306_WHITE);
  display.setCursor(20, 2);
  display.println("Light Trend");
  
  // 左上角电池图标 (表示传感器状态)
  display.drawBitmap(2, 2, icon_battery, 16, 16, SSD1306_WHITE);
  
  // 显示当前光照度
  display.setCursor(20, 12);
  display.println("Lux: " + String((int)bestLuxEMA));
  
  // 简化的护眼提示信息
  display.setCursor(20, 22);
  display.println("Too dark, find the light");
  
  // 绘制光线趋势曲线 (更多空间用于显示曲线)
  for (int i = 0; i < trendSize - 1; i++) {
    // 计算曲线上的点坐标 (增加Y轴显示范围)
    int x1 = i * (SCREEN_WIDTH / trendSize);
    int y1 = SCREEN_HEIGHT - 8 - map(lightTrend[(trendIndex + i) % trendSize], 0, 4095, 0, 25);
    int x2 = (i + 1) * (SCREEN_WIDTH / trendSize);
    int y2 = SCREEN_HEIGHT - 8 - map(lightTrend[(trendIndex + i + 1) % trendSize], 0, 4095, 0, 25);
    
    // 绘制趋势线段
    display.drawLine(x1, y1, x2, y2, SSD1306_WHITE);
  }
  
  // 底部装饰点线
  for (int i = 0; i < SCREEN_WIDTH; i += 4) {
    display.drawPixel(i, SCREEN_HEIGHT - 2, SSD1306_WHITE);
  }
  
  display.display();
}

/**
 * 蜂鸣器提示音函数 (适配新版ESP32 Arduino Core)
 * 参数：duration - 鸣叫持续时间 (毫秒)
 * 功能：播放指定时长的提示音
 * 使用新版LEDC API控制蜂鸣器
 */
void beep(int duration = 100) {
  ledcWrite(piezoPin, 127);     // 设置PWM占空比为50% (127/255)
  delay(duration);              // 持续指定时间
  ledcWrite(piezoPin, 0);       // 关闭蜂鸣器
  Serial.println("Beep! Duration: " + String(duration) + "ms");
}

/**
 * NFC检测成功提示音 (双重哔哔声)
 * 功能：播放两次短促的提示音，表示NFC卡片检测成功
 */
void beepNFCSuccess() {
  beep(150);      // 第一声
  delay(100);     // 间隔
  beep(150);      // 第二声
  Serial.println("NFC Success Sound");
}

/**
 * 番茄钟完成提示音 (三重哔哔声)
 * 功能：播放三次提示音，表示番茄钟时间到了
 */
void beepPomodoroComplete() {
  beep(200);      // 第一声
  delay(150);     // 间隔
  beep(200);      // 第二声
  delay(150);     // 间隔
  beep(300);      // 第三声（稍长）
  Serial.println("Pomodoro Complete Sound");
}

/**
 * 光线不足警告音 (长音)
 * 功能：播放较长的警告音，提醒用户光线不足
 */
void beepLightWarning() {
  beep(800);      // 长警告音
  Serial.println("Light Warning Sound");
}
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
void loop() {
  // === 读取光线传感器数据 ===
  int lightValue = analogRead(ldrPin);                    // 读取ADC值 (0-4095)
  lightTrend[trendIndex] = lightValue;                    // 保存到趋势数组
  trendIndex = (trendIndex + 1) % trendSize;              // 更新数组索引 (循环)

  // === 更新光照度EMA (指数移动平均) ===
  if (isReading) {
    bestLuxEMA = (1 - emaAlpha) * bestLuxEMA + emaAlpha * lightValue;
    bestLuxEMA = constrain(bestLuxEMA, 100, 3000);        // 限制在合理范围
  }

  unsigned long now = millis();  // 获取当前时间戳
  
  // === NFC卡片检测 (每3秒检测一次，避免I2C冲突) ===
  static unsigned long lastNFCCheck = 0;
  if (nfcInitialized && !i2cBusy && (now - lastNFCCheck > 3000)) {
    lastNFCCheck = now;
    i2cBusy = true;  // 锁定I2C总线，防止OLED和NFC同时访问
    
    uint8_t uid[7];
    uint8_t uidLength;
    
    // 尝试读取NFC卡片 (1秒超时)
    if (nfc.readPassiveTargetID(PN532_MIFARE_ISO14443A, uid, &uidLength, 1000)) {
      showNFCUIDAndSave(uid, uidLength);  // 显示NFC检测界面
      i2cBusy = false;  // 释放I2C总线
      delay(2000);      // 显示完成后等待，避免连续读取
      return;
    }
    
    i2cBusy = false;  // 释放I2C总线
  }

  // === 检查是否进入深度睡眠模式 ===
  if (lightValue < bookmarkThreshold) {
    // 保存当前会话数据
    if (isReading || isPaused) {
      unsigned long sessionMillis = accumulatedSessionMillis;
      if (isReading) sessionMillis += now - sessionStartMillis;
      totalReadingSeconds += sessionMillis / 1000;
      
      saveAdaptivePomodoro(sessionMillis);  // 保存自适应番茄钟数据
      prefs.putULong("totalSecs", totalReadingSeconds);  // 保存总阅读时间
    }
    
    // 显示睡眠界面
    if (oledInitialized && !i2cBusy) {
      display.clearDisplay();
      
      // 绘制装饰边框
      drawCornerDecorations();
      
      // 睡眠提示标题
      display.setTextSize(1);
      display.setTextColor(SSD1306_WHITE);
      display.setCursor(25, 2);
      display.println("Good Night!");
      
      // 左侧电池图标 (表示睡眠/低功耗状态)
      display.drawBitmap(6, 20, icon_battery, 16, 16, SSD1306_WHITE);
      
      // 睡眠倒计时信息
      display.setCursor(28, 20);
      display.println("Sleeping in");
      display.setCursor(35, 30);
      display.println(String(TIME_TO_SLEEP) + " seconds");
      
      // 右侧时钟图标 (表示时间)
      display.drawBitmap(106, 20, icon_clock, 16, 16, SSD1306_WHITE);
      
      // 底部睡眠装饰 "Z z z"
      display.setCursor(45, 50);
      display.setTextSize(2);
      display.println("Z z z");
      
      display.display();
      delay(1000);
    }
    
    // 进入深度睡眠
    turnOffOLED();
    esp_sleep_enable_timer_wakeup(TIME_TO_SLEEP * uS_TO_S_FACTOR);
    esp_deep_sleep_start();
  }
  
  // === 检查光线阈值 (暂停阅读) ===
  else if (lightValue < lightThreshold) {
    if (isReading) {
      // 从阅读状态转为暂停状态
      accumulatedSessionMillis += now - sessionStartMillis;
      isReading = false;
      isPaused = true;
    }
    drawTrendGraph();  // 显示光线趋势图 (包含护眼提示)
    beepLightWarning();        // 播放光线不足警告音
  }
  
  // === 正常阅读模式 ===
  else {
    if (!isReading) {
      if (inRest) {
        // === 休息时间逻辑 ===
        if (restStartMillis == 0) restStartMillis = now;  // 记录休息开始时间
        
        if (now - restStartMillis >= restDuration) {
          // 休息时间结束，开始新的阅读会话
          inRest = false;
          beep(300);                    // 播放短提示音 (休息结束)
          sessionStartMillis = now;     // 记录新会话开始时间
          accumulatedSessionMillis = 0; // 重置累积时间
          isReading = true;
        } else {
          // 显示休息界面
          if (oledInitialized && !i2cBusy) {
            display.clearDisplay();
            
            // 绘制装饰边框
            drawCornerDecorations();
            
            // 休息时间标题
            display.setTextSize(1);
            display.setTextColor(SSD1306_WHITE);
            display.setCursor(30, 2);
            display.println("Rest Time");
            
            // 左侧心形图标 (表示放松)
            display.drawBitmap(6, 15, icon_heart, 16, 16, SSD1306_WHITE);
            
            // 中央休息提示信息
            display.setTextSize(1);
            display.setCursor(28, 20);
            display.println("Take a break!");
            display.setCursor(35, 30);
            display.println("Relax...");
            
            // 右侧星星图标 (表示美好)
            display.drawBitmap(106, 15, icon_star, 16, 16, SSD1306_WHITE);
            
            // 计算并显示剩余休息时间
            unsigned long restRemaining = restDuration - (now - restStartMillis);
            int restMin = restRemaining / 60000;
            int restSec = (restRemaining / 1000) % 60;
            
            display.setCursor(35, 45);
            display.println(String(restMin) + ":" + (restSec < 10 ? "0" : "") + String(restSec));
            
            // 动态波浪线装饰 (使用sin函数创建波浪效果)
            for (int x = 0; x < SCREEN_WIDTH; x += 8) {
              int y = 55 + (sin(x * 0.3 + millis() * 0.01) * 3);
              display.drawPixel(x, y, SSD1306_WHITE);
              display.drawPixel(x + 2, y + 1, SSD1306_WHITE);
            }
            
            display.display();
          }
          delay(1000);
          return;  // 休息期间不执行后续逻辑
        }
      } else {
        // 从暂停状态恢复到阅读状态
        sessionStartMillis = now;
        isPaused = false;
        isReading = true;
      }
    } else {
      // === 阅读状态逻辑 ===
      unsigned long sessionMillis = accumulatedSessionMillis + (now - sessionStartMillis);
      
      if (sessionMillis >= adaptivePomodoroMillis) {
        // 番茄钟时间到，进入休息状态
        inRest = true;
        isReading = false;
        restStartMillis = 0;
        totalReadingSeconds += sessionMillis / 1000;
        
        saveAdaptivePomodoro(sessionMillis);              // 保存番茄钟数据
        prefs.putULong("totalSecs", totalReadingSeconds); // 保存总阅读时间
        beepPomodoroComplete();                           // 播放番茄钟完成提示音
      } else {
        // 显示阅读状态界面
        if (oledInitialized && !i2cBusy) {
          // 计算时间显示格式
          int cm = sessionMillis / 60000;                    // 当前会话分钟数
          int cs = (sessionMillis / 1000) % 60;              // 当前会话秒数
          unsigned long totalMinutes = totalReadingSeconds / 60;
          unsigned long totalHours = totalMinutes / 60;
          unsigned long totalMinsOnly = totalMinutes % 60;
          int pm = adaptivePomodoroMillis / 60000;           // 番茄钟目标分钟数
          
          // 格式化总时间字符串
          String totalStr = (totalHours > 0) ? 
            (String(totalHours) + "h " + String(totalMinsOnly) + "m") : 
            (String(totalMinsOnly) + "m");
          
          display.clearDisplay();
          
          // 绘制装饰边框
          drawCornerDecorations();
          
          // 阅读模式标题
          display.setTextSize(1);
          display.setTextColor(SSD1306_WHITE);
          display.setCursor(22, 2);
          display.println("Reading Mode");
          
          // 左侧时钟图标
          display.drawBitmap(2, 2, icon_clock, 16, 16, SSD1306_WHITE);
          
          // 当前会话时间 (大字体突出显示)
          display.setTextSize(2);
          display.setCursor(8, 15);
          display.print(String(cm) + ":" + (cs < 10 ? "0" : "") + String(cs));
          
          // 右侧动态轮播图标
          drawAnimatedIcon(108, 15, animationFrame);
          
          // 统计信息
          display.setTextSize(1);
          display.setCursor(8, 35);
          display.println("Total: " + totalStr);
          
          display.setCursor(8, 45);
          display.println("Target: " + String(pm) + " min");
          
          // 番茄钟进度条
          int progress = (sessionMillis * 100) / adaptivePomodoroMillis;
          drawProgressBar(8, 55, 112, 6, progress, 100);
          
          // NFC状态指示圆点 (实心=正常，空心=故障)
          display.fillCircle(120, 45, 2, nfcInitialized ? SSD1306_WHITE : SSD1306_BLACK);
          display.drawCircle(120, 45, 2, SSD1306_WHITE);
          
          display.display();
          animationFrame++;  // 更新动画帧计数
        }
      }
    }
  }
  
  delay(500);  // 主循环延迟，平衡响应速度和功耗
}

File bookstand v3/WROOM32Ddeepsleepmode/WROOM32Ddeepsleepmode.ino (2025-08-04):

/*
 * =======================================================================
 * ESP32 WROOM32D NFC智能阅读追踪器 - 深度睡眠修复版
 * =======================================================================
 * 
 * 修复内容：
 * - 优化睡眠检测逻辑，确保能真正进入深度睡眠
 * - 修复I2C总线未正确释放的问题
 * - 优化唤醒后的硬件重新初始化流程
 * - 降低待机功耗至约10μA（深度睡眠模式）
 * 
 * 硬件连接（从ESP32C3迁移到ESP32 WROOM32D）：
 * ESP32 WROOM32D:
 * ├── OLED SSD1306 (128x64)
 * │   ├── SDA → GPIO 21 (标准I2C)
 * │   ├── SCL → GPIO 22 (标准I2C)
 * │   ├── VCC → 3.3V
 * │   └── GND → GND
 * ├── PN532 NFC模块
 * │   ├── SDA → GPIO 21 (与OLED共享I2C总线)
 * │   ├── SCL → GPIO 22 (与OLED共享I2C总线)
 * │   ├── VCC → 3.3V
 * │   └── GND → GND
 * ├── 光敏电阻 (LDR) - 双输入设计
 * │   ├── 一端 → 3.3V
 * │   ├── 另一端 → GPIO 36 (ADC输入，精确测量)
 * │   ├── 另一端 → GPIO 26 (数字输入，唤醒用，RTC_GPIO7)
 * │   └── 两个10kΩ下拉电阻分别到GND
 * ├── 蜂鸣器模块
 * │   ├── VCC → 3.3V
 * │   ├── GND → GND
 * │   └── Signal → GPIO 5
 * └── 可选：手动唤醒按钮
 *     └── 按钮 → GPIO 2 (RTC_GPIO12) 与GND之间
 * 
 * =======================================================================
 */

#include <Arduino.h>
#include "driver/ledc.h"
#include <Preferences.h>
#include <Wire.h>
#include <Adafruit_GFX.h>
#include <Adafruit_SSD1306.h>
#include "esp_system.h"
#include "esp_sleep.h"
#include <Adafruit_PN532.h>
#include <math.h>
#include "driver/rtc_io.h"  // 添加RTC IO控制

// ===== 硬件引脚定义 (ESP32 WROOM32D - 安全版本) =====
#define SCREEN_WIDTH 128
#define SCREEN_HEIGHT 64
#define OLED_RESET -1
#define SCREEN_ADDRESS 0x3C

#define SDA_PIN 21             // ESP32标准I2C引脚
#define SCL_PIN 22             // ESP32标准I2C引脚

const int ldrPin = 36;         // 光敏电阻ADC输入 (精确测量，只读)
const int ldrWakeupPin = 26;   // 光敏电阻数字输入 (唤醒用，RTC_GPIO7)
const int buttonWakeupPin = 2; // 手动唤醒按钮 (RTC_GPIO12) - 可选
const int piezoPin = 5;        // 蜂鸣器引脚

// ===== 书籍管理配置 =====
const int MAX_BOOKS = 10;      // 最大支持书籍数量
const int BOOK_NAME_LENGTH = 20; // 书名最大长度

// 书籍数据结构
struct Book {
  String uid;                  // NFC卡片UID
  String name;                 // 书名
  unsigned long totalSeconds;  // 总阅读时间（秒）
  unsigned long lastRead;      // 最后阅读时间戳
  int sessionCount;            // 阅读会话次数
  int pomodoroCount;           // 完成的番茄钟数
  float avgSessionMinutes;     // 平均每次阅读时长（分钟）
  bool isActive;              // 是否激活（有数据）
};

// ===== 优化配置 - 修改睡眠检测参数 =====
const int lightThreshold = 1000;         // 光线阈值，低于此值认为光线不足
const int bookmarkThreshold = 200;        // 书签检测阈值，用于睡眠判断
const unsigned long STARTUP_GRACE_PERIOD = 5000;  // 启动保护时间：5秒
const int SLEEP_CHECK_COUNT = 2;          // 睡眠检测次数：减少到2次
const unsigned long SLEEP_CHECK_INTERVAL = 2000; // 睡眠检测间隔：2秒
const unsigned long IDLE_SLEEP_TIMEOUT = 30000;  // 空闲30秒后自动睡眠

// ===== 唤醒原因枚举 =====
enum WakeupReason {
  WAKEUP_TIMER,    // 定时器唤醒
  WAKEUP_LIGHT,    // 光线变化唤醒
  WAKEUP_BUTTON,   // 按钮唤醒
  WAKEUP_UNKNOWN   // 未知原因（首次启动）
};

// ===== 硬件对象初始化 =====
Adafruit_SSD1306 display(SCREEN_WIDTH, SCREEN_HEIGHT, &Wire, OLED_RESET);
Adafruit_PN532 nfc(SDA_PIN, SCL_PIN);

// ===== 书籍管理变量 =====
Book books[MAX_BOOKS];                    // 书籍数组
int currentBookIndex = -1;                // 当前书籍索引（-1表示无书）
String currentBookUID = "";               // 当前书籍UID
bool bookChanged = false;                 // 书籍是否发生切换

// ===== 状态变量 =====
String lastUID = "";                      // 上次检测到的NFC卡片UID
bool showLastUIDOnBoot = false;           // 是否在启动时显示上次的卡片
bool nfcInitialized = false;              // NFC模块是否初始化成功
bool oledInitialized = false;             // OLED屏幕是否初始化成功
bool i2cBusy = false;                     // I2C总线是否忙碌
bool isShowingNFC = false;                // 是否正在显示NFC信息
unsigned long nfcDisplayStartTime = 0;    // NFC显示开始时间
unsigned long lastActivityTime = 0;       // 最后活动时间（用于空闲检测）

// ===== 阅读状态变量 =====
bool isReading = false;                   // 是否正在阅读
bool isPaused = false;                    // 是否暂停（因光线不足）
bool inRest = false;                      // 是否在休息状态
bool isSleeping = false;                  // 是否在睡眠状态

// ===== 时间记录变量 =====
unsigned long sessionStartMillis = 0;        // 本次阅读开始时间
unsigned long accumulatedSessionMillis = 0;  // 累计阅读时间
unsigned long restStartMillis = 0;           // 休息开始时间
unsigned long totalReadingSeconds = 0;       // 总阅读时间（秒）- 所有书籍

// ===== 自适应番茄钟变量 =====
const int defaultPomodoroMin = 25;                           // 默认番茄钟时长（分钟）
unsigned long adaptivePomodoroMillis = defaultPomodoroMin * 60000UL; // 自适应番茄钟时长
unsigned long adaptiveTotalSessionTime = 0;                 // 历史总会话时间
unsigned long adaptiveSessionCount = 0;                     // 历史会话次数
const unsigned long restDuration = 5 * 60 * 1000UL;        // 休息时长：5分钟

// ===== 蜂鸣器控制 =====
unsigned long lastBeepTime = 0;              // 上次蜂鸣时间
const unsigned long beepInterval = 10000;    // 蜂鸣间隔：10秒

// ===== 数据存储 =====
Preferences prefs;
Preferences bookPrefs;  // 专门用于书籍数据存储

// ===== 光线趋势分析 =====
const int trendSize = 30;        // 趋势数据点数量
int lightTrend[trendSize] = {0}; // 光线趋势数组
int trendIndex = 0;              // 当前趋势索引
float bestLuxEMA = 0.0;          // 最佳光照指数移动平均值
const float emaAlpha = 0.05;     // EMA平滑系数
int animationFrame = 0;          // 动画帧计数

// ===== 优化的图标数据 (12x12像素，适配128x64屏幕) =====
// 书本图标 - 更清晰的12x12设计
const unsigned char icon_book[] PROGMEM = {
  0x7F, 0x80, 0x40, 0x80, 0x40, 0x80, 0x7F, 0x80, 
  0x40, 0x80, 0x40, 0x80, 0x40, 0x80, 0x40, 0x80, 
  0x40, 0x80, 0x40, 0x80, 0x40, 0x80, 0x7F, 0x80
};

// 时钟图标 - 简化设计
const unsigned char icon_clock[] PROGMEM = {
  0x1F, 0x00, 0x31, 0x80, 0x40, 0x40, 0x44, 0x40, 
  0x42, 0x40, 0x41, 0x40, 0x40, 0x40, 0x40, 0x40, 
  0x40, 0x40, 0x40, 0x40, 0x31, 0x80, 0x1F, 0x00
};

// 心形图标 - 优化形状
const unsigned char icon_heart[] PROGMEM = {
  0x00, 0x00, 0x1B, 0x00, 0x3F, 0x80, 0x7F, 0xC0, 
  0x7F, 0xC0, 0x3F, 0x80, 0x1F, 0x00, 0x0E, 0x00, 
  0x04, 0x00, 0x00, 0x00, 0x00, 0x00, 0x00, 0x00
};

// 星星图标 - 锐利设计
const unsigned char icon_star[] PROGMEM = {
  0x04, 0x00, 0x04, 0x00, 0x0E, 0x00, 0x1F, 0x00, 
  0x31, 0x80, 0x0E, 0x00, 0x1F, 0x00, 0x31, 0x80, 
  0x60, 0xC0, 0x00, 0x00, 0x00, 0x00, 0x00, 0x00
};

// 电池图标 - 清晰电量显示
const unsigned char icon_battery[] PROGMEM = {
  0x3F, 0x00, 0x21, 0x80, 0x25, 0x80, 0x25, 0x80, 
  0x25, 0x80, 0x25, 0x80, 0x25, 0x80, 0x25, 0x80, 
  0x25, 0x80, 0x21, 0x80, 0x3F, 0x00, 0x00, 0x00
};

// 新增小图标 (8x8像素，用于状态指示)
const unsigned char mini_wifi[] PROGMEM = {
  0x00, 0x18, 0x24, 0x42, 0x81, 0x99, 0x24, 0x00
};

const unsigned char mini_nfc[] PROGMEM = {
  0x3C, 0x42, 0x42, 0x5A, 0x5A, 0x42, 0x42, 0x3C
};

const unsigned char mini_light[] PROGMEM = {
  0x08, 0x49, 0x2A, 0x1C, 0x1C, 0x2A, 0x49, 0x08
};

// 数字字体 (5x7像素，用于大号数字显示)
const unsigned char numbers_5x7[][5] PROGMEM = {
  {0x3E, 0x41, 0x41, 0x41, 0x3E}, // 0
  {0x00, 0x42, 0x7F, 0x40, 0x00}, // 1
  {0x42, 0x61, 0x51, 0x49, 0x46}, // 2
  {0x21, 0x41, 0x45, 0x4B, 0x31}, // 3
  {0x18, 0x14, 0x12, 0x7F, 0x10}, // 4
  {0x27, 0x45, 0x45, 0x45, 0x39}, // 5
  {0x3C, 0x4A, 0x49, 0x49, 0x30}, // 6
  {0x01, 0x71, 0x09, 0x05, 0x03}, // 7
  {0x36, 0x49, 0x49, 0x49, 0x36}, // 8
  {0x06, 0x49, 0x49, 0x29, 0x1E}  // 9
};
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
